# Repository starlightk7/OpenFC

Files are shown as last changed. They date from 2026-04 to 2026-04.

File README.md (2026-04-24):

# OpenFC

## Introduction

This repository contains OSHW Reproduction Parts related to the Famicom (FC) game console under the umbrella name OpenFC.

These parts are freely available under the terms of the [CERN-OHL-S](https://github.com/starlightk7/OpenFC/blob/main/LICENSE) license for you to use, study, modify, or sell. The source files are provided as-is with no warranty or entitlement for support to you or any users that you sell manufactured boards to. See [LICENSE](https://github.com/starlightk7/OpenFC/blob/main/LICENSE) and [NOTICE](https://github.com/starlightk7/OpenFC/blob/main/NOTICE) for details. Please carefully read these files to understand your obligations if you choose to distribute this project or modifications of it.

## Sample Build



## Usage

Suggested usage for the documents and boards in this repository:

* Studying the hardware and learning about it's function
* Aiding repairs and failure diagnostics through the created [schematics](https://starlightk7.github.io/OpenFC/#/schematic) and boardviews
* Repairing broken consoles via replacement, reproduction boards and tested replacement [BOMs](https://starlightk7.github.io/OpenFC/#/bom).
* Building a customized console as a DIY project, for hobby or educational purposes.

## Documentation

Please read the [documentation](https://starlightk7.github.io/OpenFC/) carefully before using the project.

You can also watch an HVC install video from [1upRestorations (English)](https://youtu.be/V8x1_Q33Uts)

## Getting a Board

The project officially distributes boards from [Japan (inexpensive international shipping available)](https://ko-fi.com/starlightk7/shop), the [US](https://1uprestorations.com/collections/console-mod-parts/) and the [UK](https://www.retroupgrades.co.uk/). If you just wish to simply obtain a board for yourself, it will often be cheaper than ordering from the fab directly.

***Support is offered to those who purchased a board from a vendor listed below. No support is provided for fabricating these files on your own. If you choose that route, you should understand what you are doing and are responsible for ensuring it is done right. I am not responsible for any defects that may arise from improperly manufacturing these files, or for defects arising from modifications made by you or your PCB fab during manufacturing. If you produce these boards for sale without becoming an authorized distributor, you are responsible for any and all customer support related to the product as well as your compliance with the project's license***. 

If you have any questions about this, feel free to contact with questions. If you are interested in becoming an authorized distributor for your region, and thus gaining support for your users, please contact me via Discord or Twitter.

The ultimate goal of this project is to eventually document and reproduce all models, but it will take quite some time. If you believe in the long term goal, consider subscribing on Ko-Fi; labor aside, donor boards to research, prototypes, and parts are all expensive, and those funds will help offset those costs to complete more boards.



Feel free to come chat with us on Discord: 

All boards in this project are ~40 years old at the time of writing. All relevant patents worldwide have long expired. This project is not affiliated with or endorsed by the big N.

## Commissions

I do not have time to build commissions on a regular basis, however, there are members of the retro community whom offer this service.

| US/Canada |
|-----------|
| [1upRestorations (United States)'](https://1uprestorations.com/) |

## Disclaimer

**WARNING:** Doing a full build is an advanced project. Please carefully read the documentation and required skills and experience before purchasing or ordering a board. Purchasing boards and parts does not guarantee that you can be successful in doing a build. Significant experience in soldering and desoldering, along with a variety of tools are necessary. Your first build will likely not work on its first boot. Patience, analysis, and debugging will likely be necessary to bring the unit online. Order at your own risk. The author provides no guarantee of your success, and also cannot guarantee that any given vendor can fabricate these boards correctly. If you are ordering boards, please consult with your target vendor before ordering if you wish to order a board.

## Parts Index

### Motherboards

| Part Number | Description | Region | Status| Japan | United States | United Kingdom |
|---|---|---|---|---|---|---|
| HVC-CPU-01 | AV Famicom / New Famicom | NTSC-J | Need Donor  | N/A | N/A | N/A |
| HVC-CPU-02 | AV Famicom / New Famicom | NTSC-J | Need Donor  | N/A | N/A | N/A |
| HVC-CPU-03 | AV Famicom / New Famicom | NTSC-J | Planned | N/A | N/A | N/A |
| HVC-CPU-04 | AV Famicom / New Famicom | NTSC-J | Planned | N/A | N/A | N/A |
| HVC-CPU-05 | AV Famicom / New Famicom | NTSC-J | Planned | N/A | N/A | N/A |
| HVC-CPU-06 | AV Famicom / New Famicom | NTSC-J | Planned | N/A | N/A | N/A |
| HVC-CPU-07 (1984) | The most common HVC motherboard. Most often comes with Rev. E chips. | NTSC-J | Released | [Ko-Fi (Direct)](https://ko-fi.com/starlightk7/shop), [eBay (Direct)](https://www.ebay.com/usr/starlightk7), [Etsy (Direct)](https://starlightretro.etsy.com) | [1upRestorations](https://1uprestorations.com/collections/console-mod-parts) | [RetroUpgrades](https://www.retroupgrades.co.uk/product/opensfc-shvc-bundle) |
| HVC-CPU-GPM-01 | Redesign that worked on lowering EMI for VCCI compliance | NTSC-J | Planned | N/A | N/A | N/A |
| HVC-CPU-GPM-02 | Redesign that worked on lowering EMI for VCCI compliance | NTSC-J | Planned | N/A | N/A | N/A |
| HVCN-CPU-01 | AV Famicom / New Famicom | NTSC-J | Need Donor  | N/A | N/A | N/A |
| HVCN-CPU-02 | AV Famicom / New Famicom | NTSC-J | In Progress | N/A | N/A | N/A |

### Power AV

| Part Number | Description | Region | Status| Japan | United States | United Kingdom |
|---|---|---|---|---|---|---|
| KP-782 | Early Type Original Power / RF Board | NTSC-J | Planned | N/A | N/A | N/A |
| KP-917 | Late Type Original Power / RF Board | NTSC-J | In Testing | N/A | N/A | N/A |
| OFC-PWRAV-01 | Original Design. Backport of SFC-style Power/Audio circuit w/ THS7314 for Composite Video. | NTSC-J | Released | [Ko-Fi (Direct)](https://ko-fi.com/starlightk7/shop), [eBay (Direct)](https://www.ebay.com/usr/starlightk7), [Etsy (Direct)](https://starlightretro.etsy.com) | [1upRestorations](https://1uprestorations.com/collections/console-mod-parts) | [RetroUpgrades](https://www.retroupgrades.co.uk/product/opensfc-shvc-bundle) |

### Controllers

| Part Number | Description | Region | Status| Japan | United States | United Kingdom |
|---|---|---|---|---|---|---|
| 56.8231A | Found in Early Circle Button Controllers Pre-NES Launch | NTSC-J | Planned | N/A | N/A | N/A |
| 56.8231B | Found in Most Circle Buttton Controllers. Official NES Support | NTSC-J / NTSC-U | Released | [Ko-Fi (Direct)](https://ko-fi.com/starlightk7/shop), [eBay (Direct)](https://www.ebay.com/usr/starlightk7), [Etsy (Direct)](https://starlightretro.etsy.com) | [1upRestorations](https://1uprestorations.com/collections/console-mod-parts) | [RetroUpgrades](https://www.retroupgrades.co.uk/product/opensfc-shvc-bundle) |
| 56.8232A  | Circle Button Player 2 Controller | NTSC-J | Released | [Ko-Fi (Direct)](https://ko-fi.com/starlightk7/shop), [eBay(Direct)](https://www.ebay.com/usr/starlightk7) | [1upRestorations](https://1uprestorations.com/collections/console-mod-parts) | [RetroUpgrades](https://www.retroupgrades.co.uk/) |

### Cartridges

There are none currently in progress, but they are planned for future.

### Accessories

There are none currently in progress, but they planned for future.

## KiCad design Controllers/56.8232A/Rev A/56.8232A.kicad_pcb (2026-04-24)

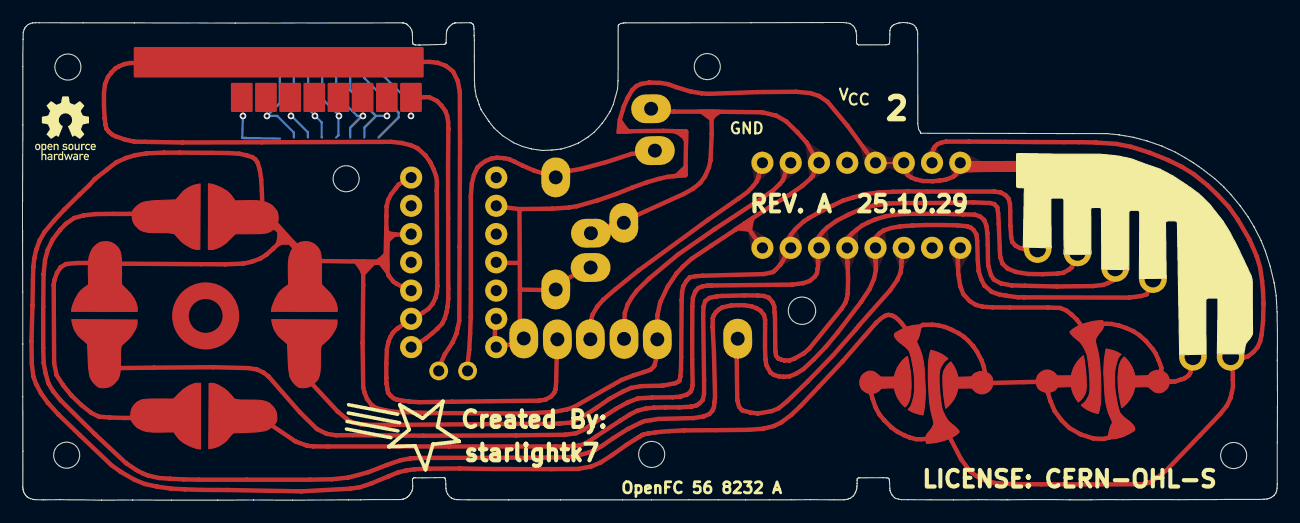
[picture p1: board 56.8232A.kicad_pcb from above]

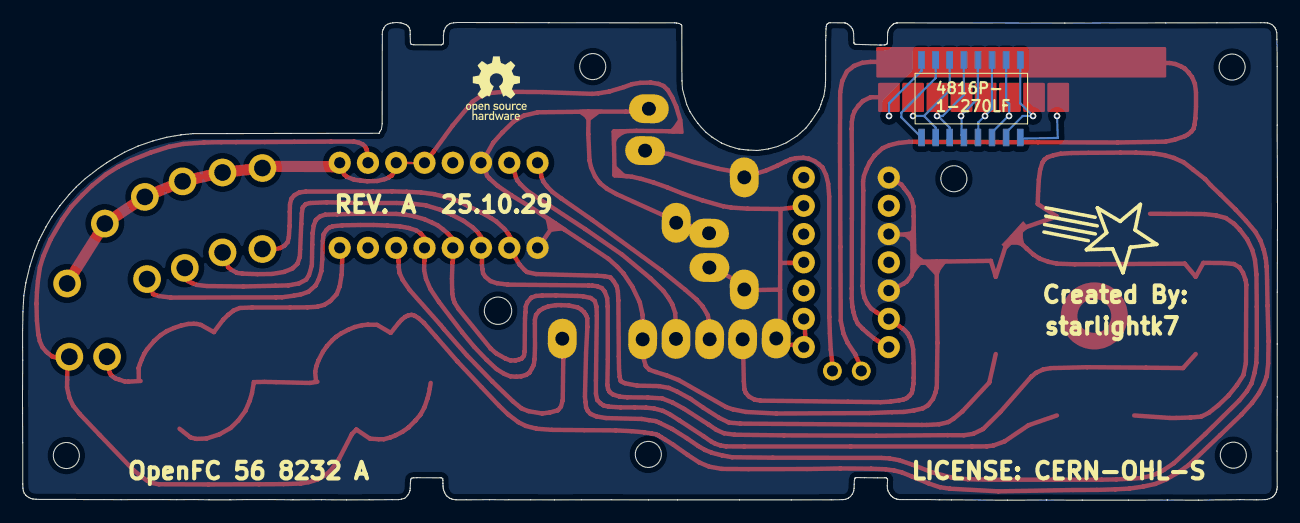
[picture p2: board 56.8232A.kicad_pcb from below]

Board: 2 copper layers, 113.0 x 43.0 mm, 23 parts (4 on the bottom side), 21 nets.

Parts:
C1: 0.33uf; C_THT_Small
IC1: IC4021
IC2: MIC_IC
J1, J2, J3, J4, J5, J7, J8, J9, J11, J12, J13: +5V; P1_Wire
R1: 2.2k; R_THT_Alt_Long
RN1: 40k x6; P2_CarbonTraces
RN2: 27ohm x8 SOIC; R_Array_08_SOIC16
S1: LEFT; P1_DPad
S3: UP; P1_DPad
S4: RIGHT; P1_DPad
S5: DOWN; P1_DPad
S9: B; P1_AB
S10: A; P1_AB

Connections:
GND: IC1.8 (GND), IC1.11 (GND), IC2.3 (I2), IC2.5 (I3), IC2.7 (VSS), J4.1, J8.1, J9.1, J12.1, S1.2 (Out), S3.2 (Out), S4.2 (Out), S5.2 (Out), S9.2 (Out), S10.2 (Out)
unnamed: IC1.1 (A), RN1.10, S10.1 (In)
unnamed: IC1.15 (B), RN1.12, S9.1 (In)
unnamed: IC1.10 (CLK), J3.1
unnamed: IC1.3 (Data), J13.1
unnamed: IC1.5 (Down), RN1.6, S5.1 (In)
unnamed: IC1.9 (Latch), J2.1
unnamed: IC1.6 (Left), RN1.4, S1.1 (In)
unnamed: IC1.7 (Right), RN1.2, S4.1 (In)
unnamed: IC1.4 (Up), RN1.8, S3.1 (In)
unnamed: IC2.1 (I1), RN2.16 (R1.2)
unnamed: C1.2, IC2.2 (O1), J1.1
unnamed: C1.1, J11.1, R1.1
unnamed: RN2.1 (R1.1), RN2.15 (R2.2)
unnamed: RN2.2 (R2.1), RN2.14 (R3.2)
unnamed: RN2.3 (R3.1), RN2.13 (R4.2)
unnamed: RN2.4 (R4.1), RN2.12 (R5.2)
unnamed: RN2.5 (R5.1), RN2.11 (R6.2)
unnamed: RN2.6 (R6.1), RN2.10 (R7.2)
unnamed: RN2.7 (R7.1), RN2.9 (R8.2)
VCC: IC1.13 (Start), IC1.14 (Sel.), IC1.16 (5V), IC2.9 (I4), IC2.11 (I5), IC2.13 (I6), IC2.14 (VDD), J5.1, J7.1, R1.2, RN1.1, RN1.3, RN1.5, RN1.7, RN1.9, RN1.11

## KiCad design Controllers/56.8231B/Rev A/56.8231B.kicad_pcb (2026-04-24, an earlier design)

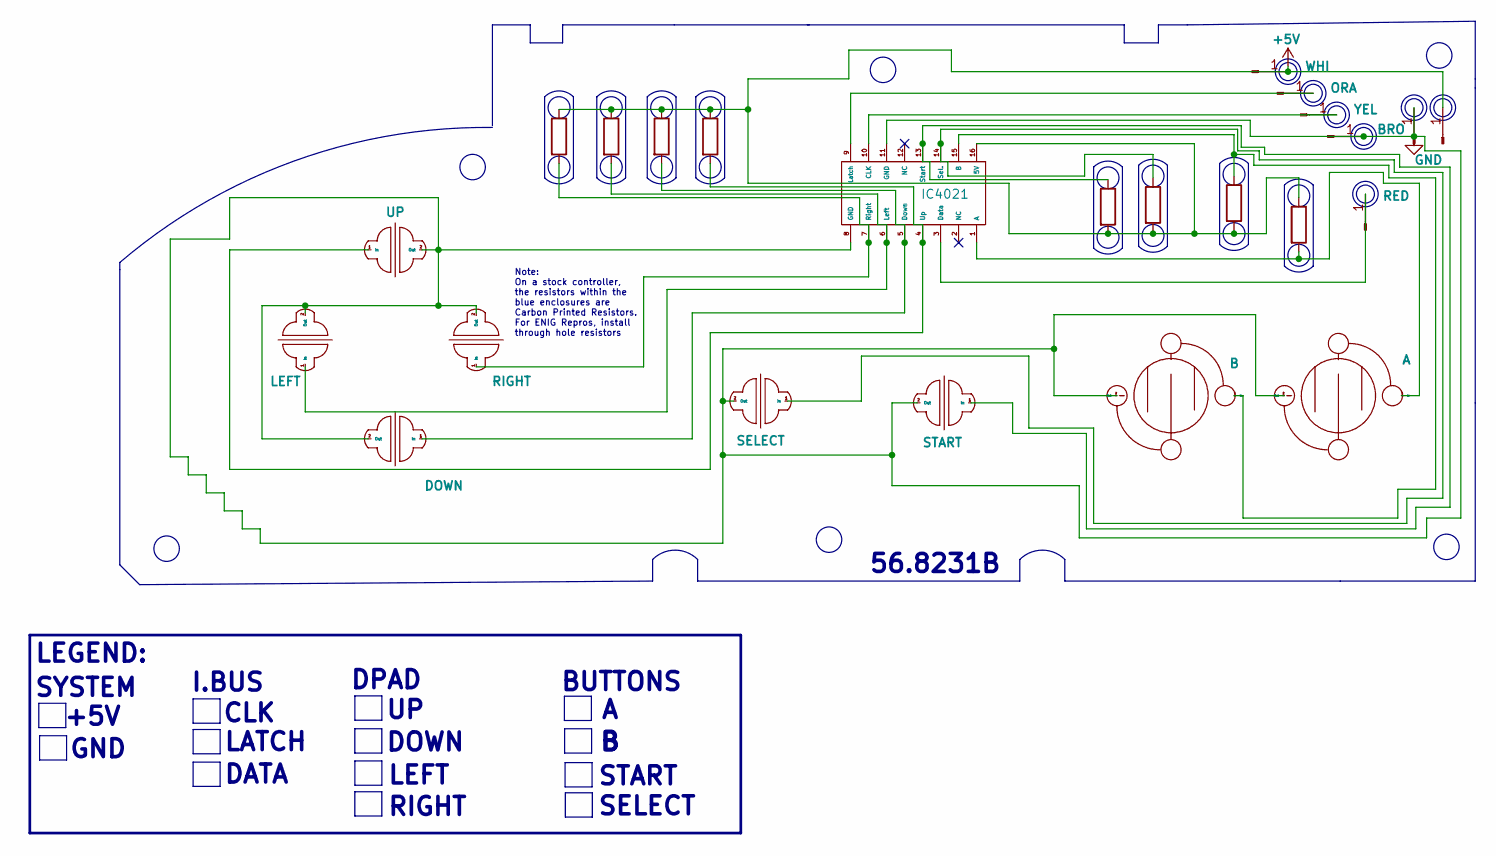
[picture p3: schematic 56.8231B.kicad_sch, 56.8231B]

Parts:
IC1: IC4021
J1: ORA; P1_Wire
J2: WHI; P1_Wire
J3: YEL; P1_Wire
J4: BRO; P1_Wire
J5: +5V; P1_Wire
J6: GND; P1_Wire
J7: RED; P1_Wire
R1, R2, R3, R4, R5, R6, R7, R8: R; CarbonResistor
S1: LEFT; P1_DPad
S2: SELECT; P1_SelectStart
S3: UP; P1_DPad
S4: RIGHT; P1_DPad
S5: DOWN; P1_DPad
S6: START; P1_SelectStart
S9: B; P1_AB
S10: A; P1_AB

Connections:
+5V: IC1.16 (5V), J2.1, J5.1, R1.1, R2.1, R3.1, R4.1, R5.2, R6.2, R7.2, R8.1
GND: IC1.8 (GND), IC1.11 (GND), J4.1, J6.1, S1.2 (Out), S2.2 (Out), S3.2 (Out), S4.2 (Out), S5.2 (Out), S6.2 (Out), S9.2 (Out), S10.2 (Out)
unnamed: IC1.1 (A), R8.2, S10.1 (In)
unnamed: IC1.15 (B), R7.1, S9.1 (In)
unnamed: IC1.10 (CLK), J3.1
unnamed: IC1.3 (Data), J7.1
unnamed: IC1.5 (Down), R3.2, S5.1 (In)
unnamed: IC1.9 (Latch), J1.1
unnamed: IC1.6 (Left), R2.2, S1.1 (In)
unnamed: IC1.7 (Right), R1.2, S4.1 (In)
unnamed: IC1.14 (Sel.), R6.1, S2.1 (In)
unnamed: IC1.13 (Start), R5.1, S6.1 (In)
unnamed: IC1.4 (Up), R4.2, S3.1 (In)

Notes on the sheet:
BUTTONS
START
LEFT
DOWN
Note: On a stock controller, the resistors within the blue enclosures are Carbon Printed Resistors. For ENIG Repros, install through hole resistors
DATA
56.8231B
LATCH
SELECT
DPAD
LEGEND:
+5V
SYSTEM
CLK
GND
RIGHT
I.BUS

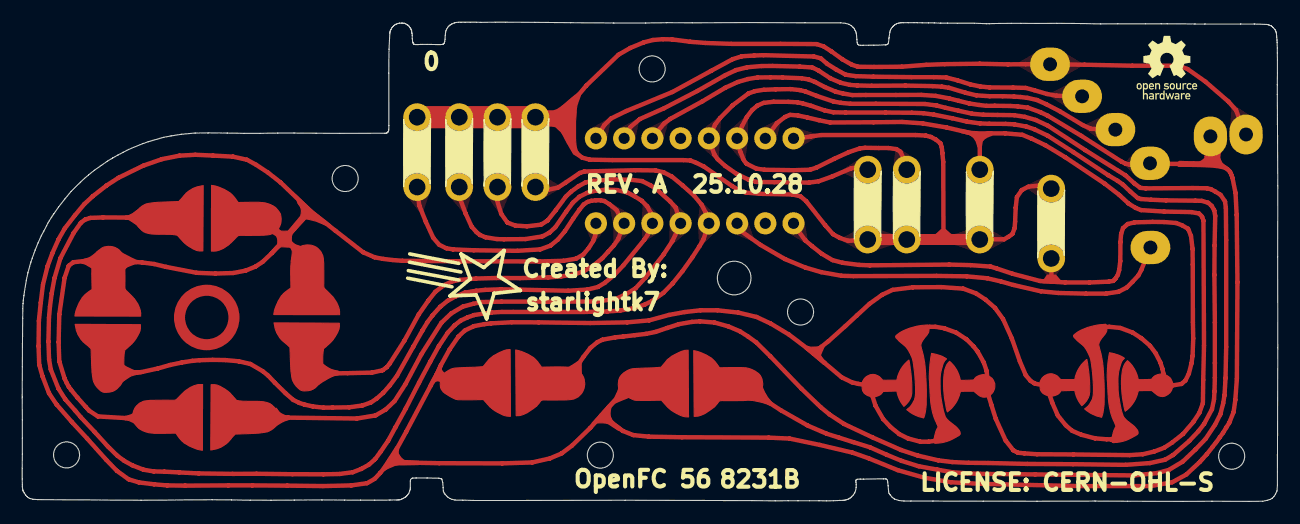
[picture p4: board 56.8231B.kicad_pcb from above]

Board: 2 copper layers, 113.2 x 43.2 mm, 24 parts (1 on the bottom side), 13 nets.

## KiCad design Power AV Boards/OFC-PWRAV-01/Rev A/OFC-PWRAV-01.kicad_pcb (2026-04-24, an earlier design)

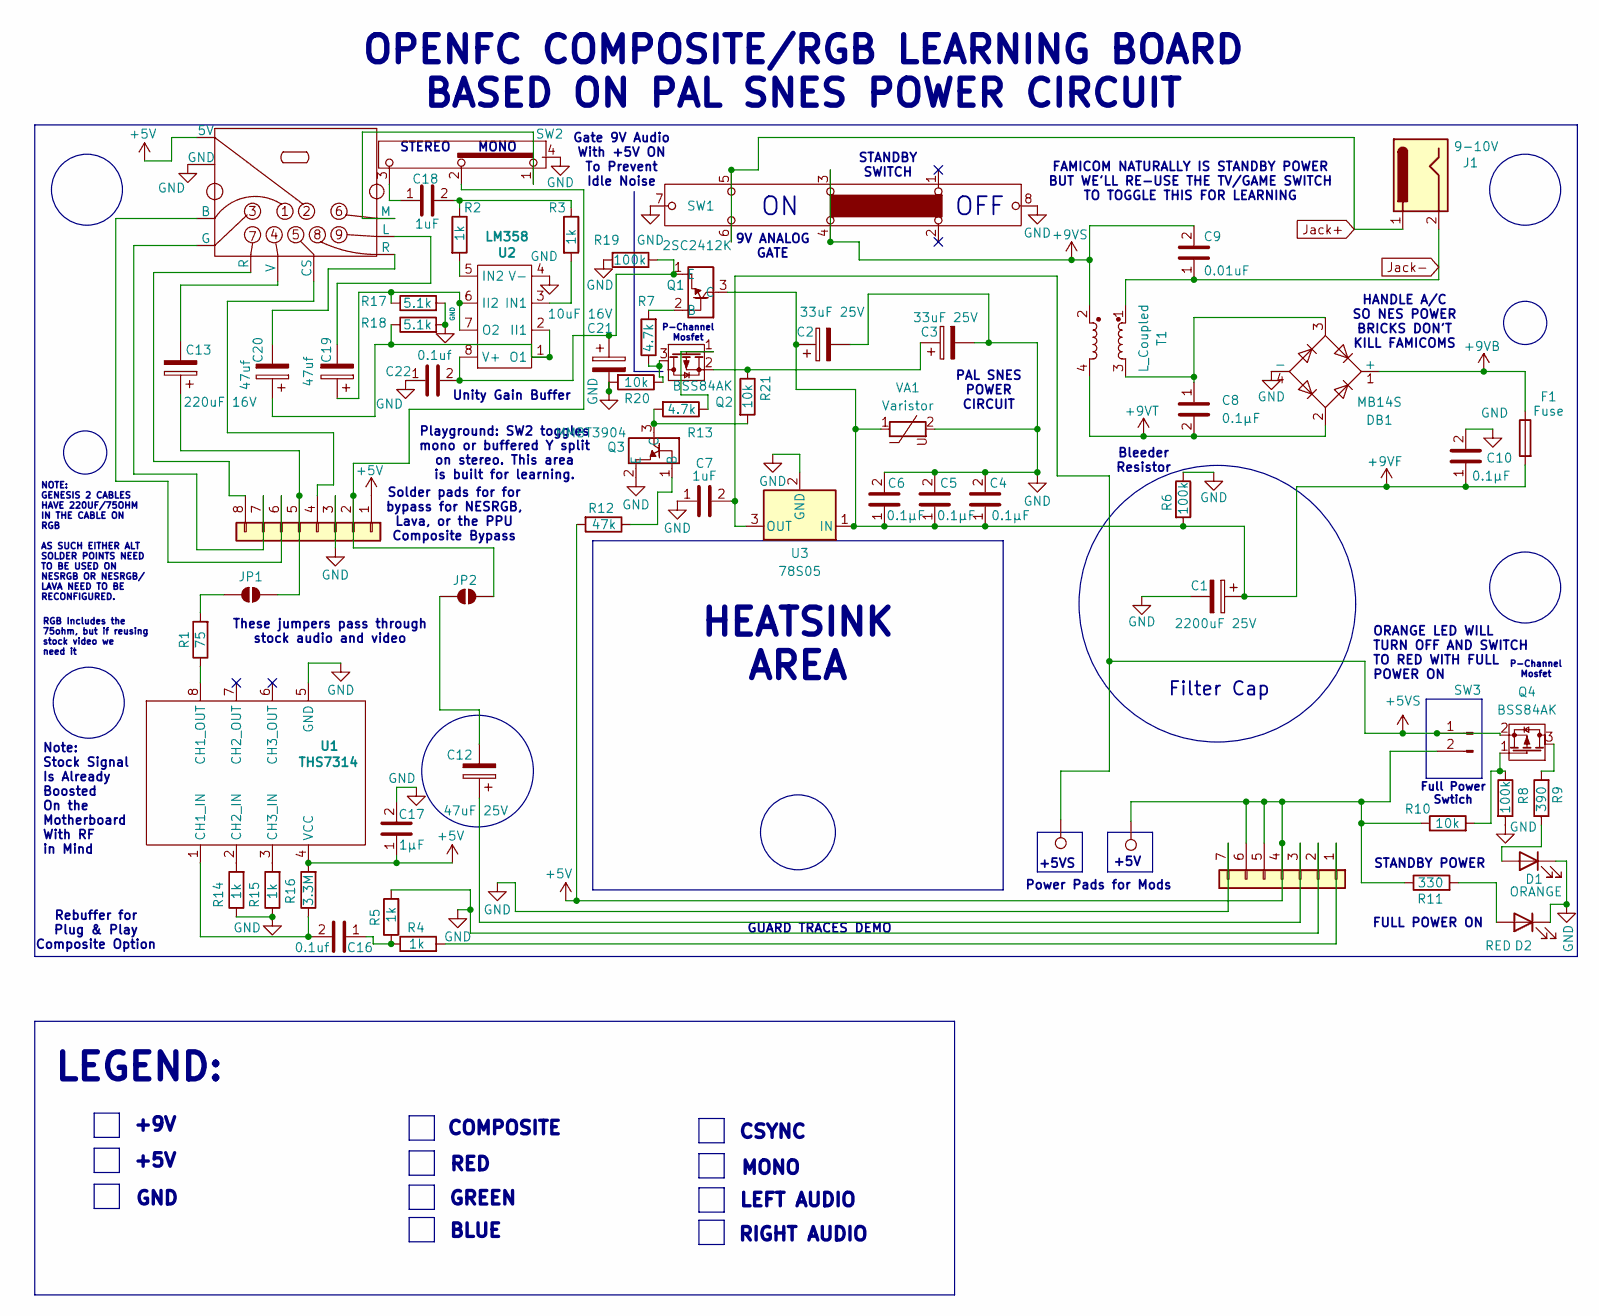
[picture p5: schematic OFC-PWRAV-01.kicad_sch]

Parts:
C1: 2200uF 25V; SFC_FilterCap
C2, C3: 33uF 25V; CP_Elec_6.3x3
C4, C5, C6, C8, C10: 0.1µF; SFC_SMD_0805
C7, C18: 1uF; SFC_SMD_0805
C9: 0.01uF; SFC_SMD_0805
C12: 47uF 25V; SFC_THT_Cap
C13: 220uF 16V; SFC_THT_Cap_S
C16, C22: 0.1uf; SFC_SMD_0805
C17: 1µF; SFC_SMD_0805
C19, C20: 47uf; SFC_THT_Cap
C21: 10uF 16V; SFC_SMD_CAP_S
D1: ORANGE; SFC_SMD_0805
D2: RED; SFC_SMD_0805
DB1: MB14S; Diode_Bridge_Vishay_MBLS
F1: Fuse; SFC_FUSE
J1: 9-10V; SFC_DCJack
J2, J3: Conn_01x07; HVC_Ribbon
J4: MD-90SM; DIN_9P; PARTREV 02/18/2022
JP1, JP2: SolderJumper_2_Open; SolderJumper-2_P1.3mm_Open_Pad1.0x1.5mm
Q1: 2SC2412K; Q_SOT
Q2, Q4: BSS84AK; Q_SOT_23
Q3: MMBT3904; Q_SOT_23
R1: 75; SFC_SMD_0805
R2, R3, R4, R5, R14, R15: 1k; SFC_SMD_0805
R6, R8, R19: 100k; SFC_SMD_0805
R7, R13: 4.7k; SFC_SMD_0805
R9: 390; SFC_SMD_0805
R10, R20, R21: 10k; SFC_SMD_0805
R11: 330; SFC_SMD_0805
R12: 47k; SFC_SMD_0805
R16: 3.3M; SFC_SMD_0805
R17, R18: 5.1k; SFC_SMD_0805
SW1: SW_TV_Game
SW2: SW_Channel
SW3: Conn_01x02_Pin; SFC_PowerSwitchConnector
T1: L_Coupled; SFC_T1
TP1, TP2: TestPoint; TestPoint_Pad_1.0x1.0mm
U1: THS7314; THS7134
U2: LM358; OpAmp
U3: 78S05; 7805_Heatsink
VA1: Varistor; SFC_SMD_Varistor

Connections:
+5V: C17.1, J2.4, J2.5, J2.6, J3.1 (+5VA), J4.2 (5V), R10.1, R11.1, R12.2, R16.2, SW3.2, TP2.1, U1.4 (VCC)
+5VS: C7.2, Q4.2 (S), SW3.1, TP1.1, U3.3 (OUT)
+9VB: DB1.1 (+), F1.1
+9VF: C1.1, C2.1, C4.1, C5.1, C6.1, C10.1, F1.2, Q1.3 (C), R6.2, U3.1 (IN), VA1.1
+9VS: C9.2, SW1.3, SW1.4, T1.2
+9VT: C8.2, DB1.2, T1.4
GND: C1.2, C2.2, C3.2, C4.2, C5.2, C6.2, C7.1, C10.2, C17.2, C21.2, C22.1, D1.1 (K), D2.1 (K), DB1.4 (-), J2.2, J2.7, J3.3 (AGND), J4.10 (GND), Q3.2 (E), R5.2, R6.1, R8.2, R14.1, R15.1, R17.2, R18.2, R19.2, R20.2, SW1.7, SW1.8, SW2.4, U1.5 (GND), U2.4 (V-), U3.2 (GND), VA1.2
Jack+: J1.1, SW1.5, SW1.6
Jack-: C9.1, J1.2, T1.1
unnamed: C8.1, DB1.3, T1.3
unnamed: C16.1, R4.1, R5.1
unnamed: C18.1, SW2.3
unnamed: C18.2, R2.1, R3.1
unnamed: C20.2, J4.8 (R)
unnamed: D1.2 (A), R9.1
unnamed: D2.2 (A), R11.2
unnamed: J2.1, R4.2
unnamed: C12.1, J2.3
unnamed: J3.2 (A), JP2.2 (B), SW2.2
unnamed: J3.4 (CS), J4.5 (CS)
unnamed: J3.7 (G), J4.3 (G)
unnamed: J3.8 (R), J4.7 (R)
unnamed: J3.6 (B), J4.1 (B)
unnamed: C19.2, J4.9 (L)
unnamed: J4.6 (M), SW2.1
unnamed: C13.2, J4.4 (V)
unnamed: JP1.1 (A), R1.2
unnamed: C13.1, J3.5 (B), JP1.2 (B)
unnamed: C12.2, JP2.1 (A)
unnamed: Q1.2 (B), R7.2
unnamed: C21.1, C22.2, Q1.1 (E), R19.1, U2.8 (V+)
unnamed: Q2.3 (D), R7.1, R20.1
unnamed: Q2.1 (G), R13.1
unnamed: C3.1, Q2.2 (S), R21.1
unnamed: Q3.1 (B), R12.1
unnamed: Q3.3 (C), R13.2, R21.2
unnamed: Q4.3 (D), R9.2
unnamed: Q4.1 (G), R8.1, R10.2
unnamed: C16.2, R16.1, U1.1 (CH1_IN)
unnamed: R1.1, U1.8 (CH1_OUT)
unnamed: R14.2, U1.2 (CH2_IN)
unnamed: R15.2, U1.3 (CH3_IN)
unnamed: C20.1, R18.1, U2.1 (O1), U2.2 (II1)
unnamed: C19.1, R17.1, U2.6 (II2), U2.7 (O2)
unnamed: R3.2, U2.3 (IN1)
unnamed: R2.2, U2.5 (IN2)

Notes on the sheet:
STEREO
STANDBY POWER
Solder pads for for bypass for NESRGB, Lava, or the PPU Composite Bypass
RIGHT AUDIO
9V ANALOG GATE
HANDLE A/C SO NES POWER BRICKS DON'T KILL FAMICOMS
+5V
Filter Cap
RGB Includes the 75ohm, but if reusing stock video we need it
P-Channel Mosfet
ORANGE LED WILL TURN OFF AND SWITCH TO RED WITH FULL POWER ON
RED
MONO
LEFT AUDIO
Unity Gain Buffer
PAL SNES POWER CIRCUIT
OFF
GUARD TRACES DEMO
FAMICOM NATURALLY IS STANDBY POWER BUT WE'LL RE-USE THE TV/GAME SWITCH TO TOGGLE THIS FOR LEARNING
Gate 9V Audio With +5V ON To Prevent Idle Noise
+5VS
NOTE: GENESIS 2 CABLES HAVE 220UF/75OHM IN THE CABLE ON RGB AS SUCH EITHER ALT SOLDER POINTS NEED TO BE USED ON NESRGB OR NESRGB/ LAVA NEED TO BE RECONFIGURED.
Note: Stock Signal Is Already Boosted On the Motherboard With RF in Mind
Playground: SW2 toggles mono or buffered Y split on stereo. This area is built for learning.
Rebuffer for Plug & Play Composite Option
COMPOSITE
CSYNC
Bleeder Resistor
HEATSINK AREA
Power Pads for Mods
These jumpers pass through stock audio and video
Full Power Swtich
LEGEND:
GND
+9V
STANDBY SWITCH
OPENFC COMPOSITE/RGB LEARNING BOARD BASED ON PAL SNES POWER CIRCUIT
GREEN
BLUE
FULL POWER ON

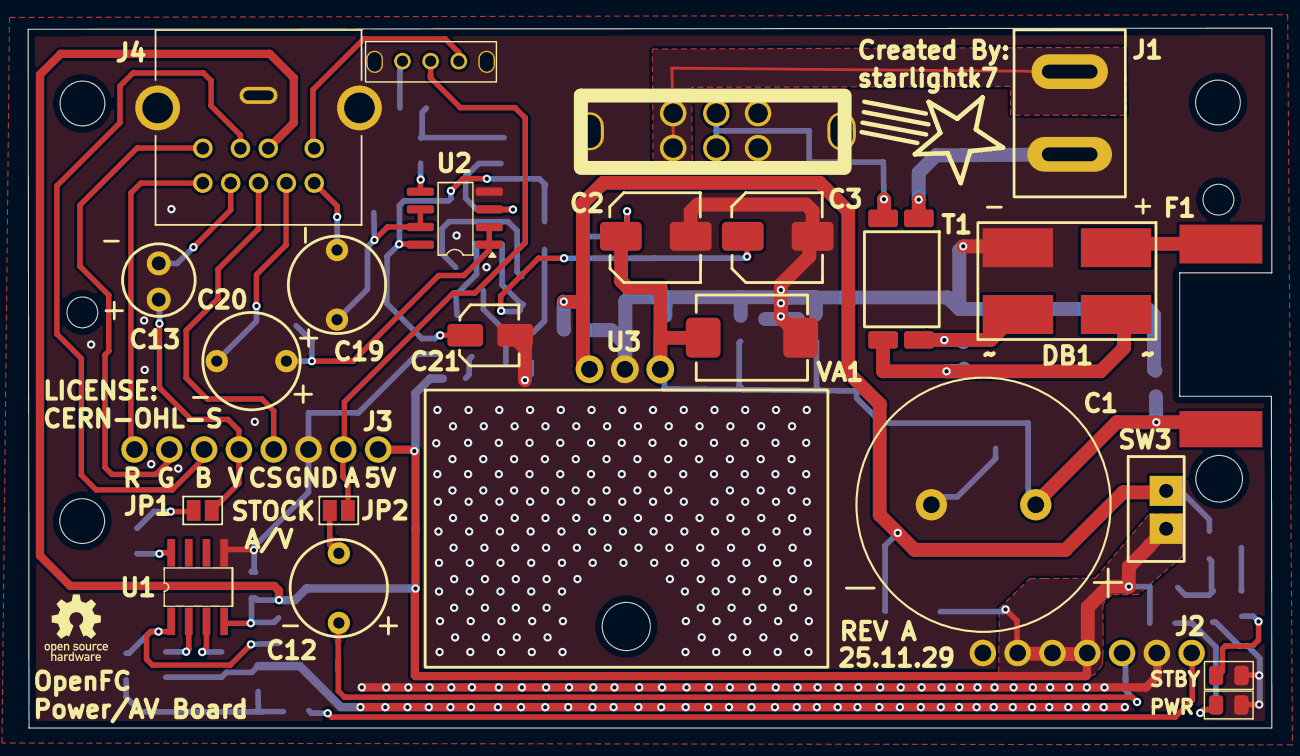
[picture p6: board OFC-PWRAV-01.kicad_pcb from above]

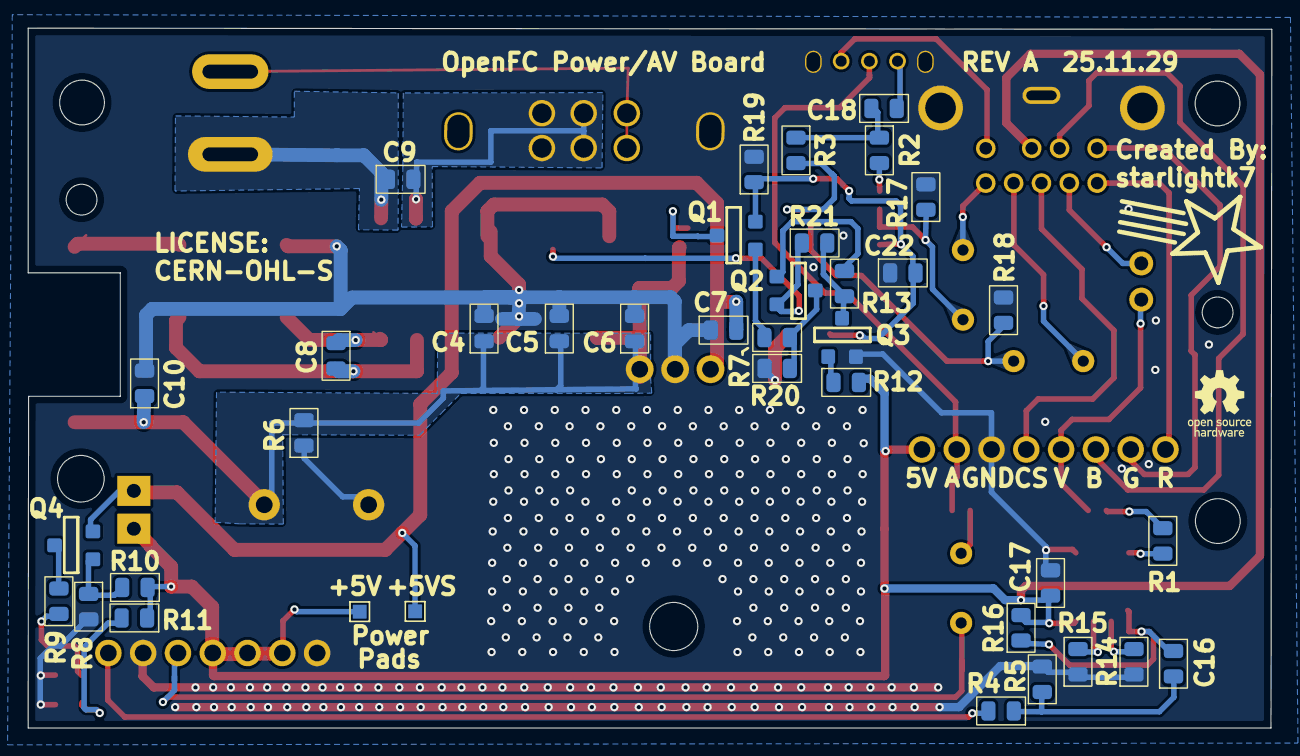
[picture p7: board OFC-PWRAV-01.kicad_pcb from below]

Board: 4 copper layers, 89.3 x 50.3 mm, 64 parts (38 on the bottom side), 46 nets.

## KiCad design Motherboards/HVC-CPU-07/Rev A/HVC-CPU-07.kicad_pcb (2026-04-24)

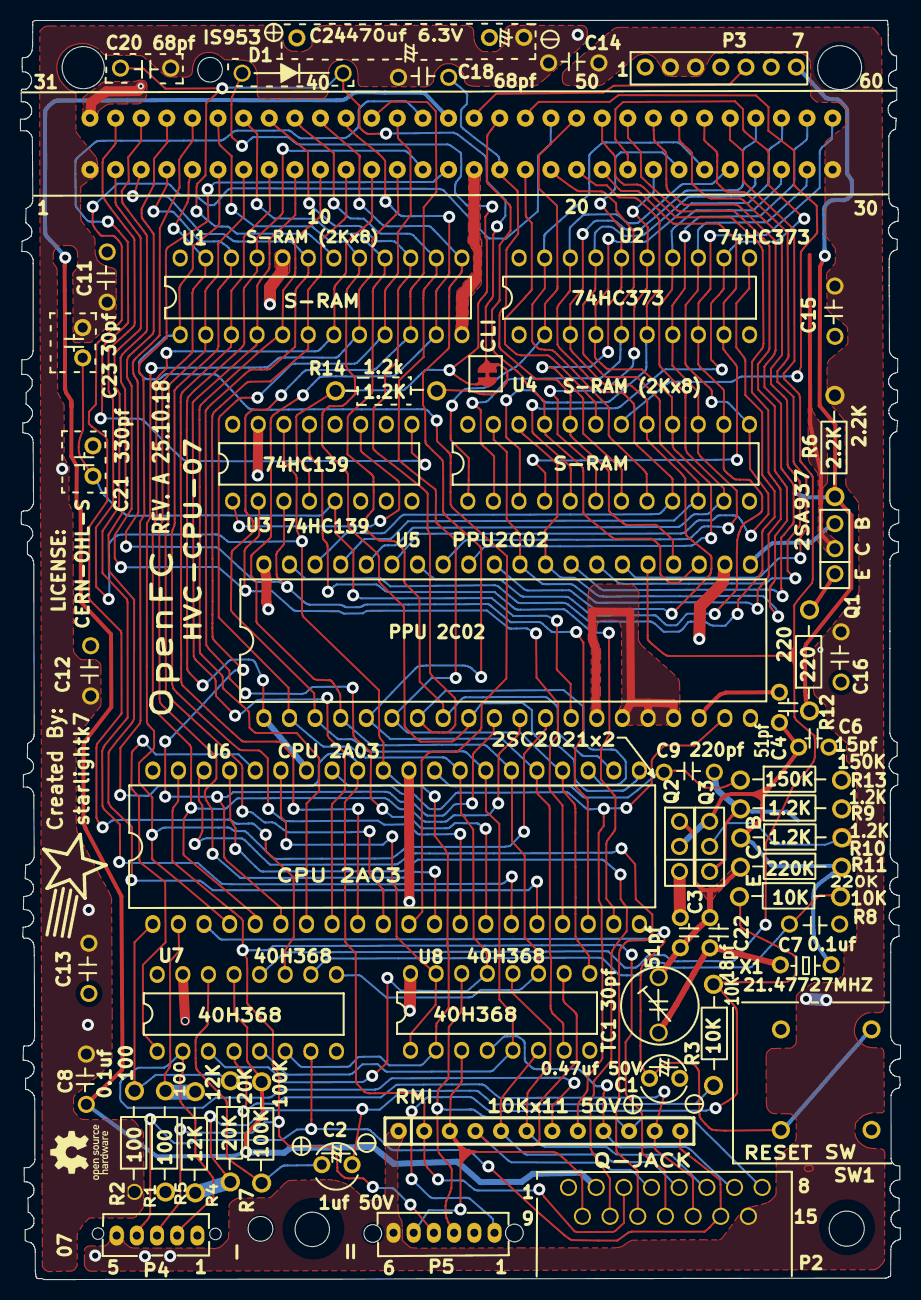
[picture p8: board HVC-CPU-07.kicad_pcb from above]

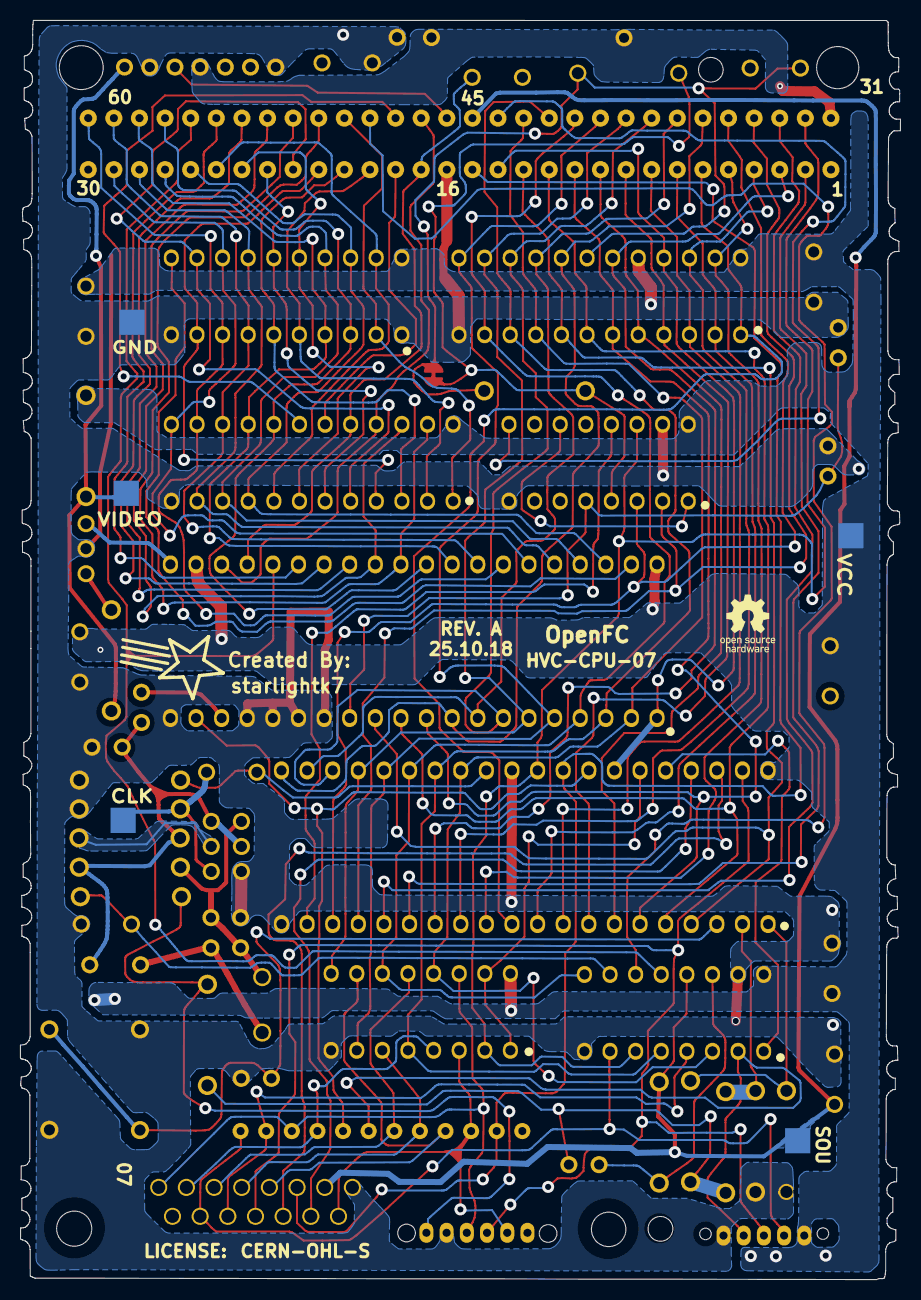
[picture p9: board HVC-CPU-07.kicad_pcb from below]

Board: 4 copper layers, 87.3 x 124.9 mm, 60 parts (5 on the bottom side), 95 nets.

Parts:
C1: 0.47uf 50V; C_Electrolytic
C2: 1uf 50V; C_Electrolytic_Small
C3, C4: 51pf; C_THT_Small
C6: 15pf; C_THT_Small
C7, C8, C11, C12, C13, C14, C15, C16: 0.1uf; C_THT
C9: 220pf; C_THT
C18, C20: 68pf; C_THT
C21: 330pf; C_THT_Small
C22: 18pf; C_THT_Small
C23: 30pf; C_THT_Small
C24: 470uf 6.3V; C_Axial
D1: Diode_THT
P1: 60PinCartSlot
P2: Q-JACK; D-JACK
P3: Conn_01x07; P3_PowerRibbon
P4: Conn_01x05; P4_Controller1
P5: Conn_01x06; P5_Controller2
Q1: 2SA937; Q_THT
Q2, Q3: 25C2021; Q_THT
R1, R2: 100; R_THT
R3, R8: 10K; R_THT
R4: 20K; R_THT
R5: 12K; R_THT
R6: 2.2K; R_THT
R7: 100K; R_THT
R9, R10, R14: 1.2K; R_THT
R11: 220K; R_THT
R12: 220; R_THT
R13: 150K; R_THT
RM1: 10Kx11 50V; R_Array_SIP12
SW1: RESET SW; RESET_SW
TC1: 30pf; TC1
TP1, TP2, TP3, TP4, TP5: TestPoint_Pad_2.5x2.5mm
U1, U4: S-RAM (2Kx8); S-RAM_2Kx8
U2: 74HC373
U3: 74HC139; 74HC139_40H368
U5: PPU 2C02; CPU_PPU
U6: CPU 2A03; CPU_PPU
U7, U8: 40H368; 74HC139_40H368
X1: 21.47727MHZ; Crystal

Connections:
1G: U3.1 (1G), U3.11 (2Y1)
A.IN: C8.1, P1.45 (A.IN), P2.2, R7.1, TP5.1, U7.13 (2Y2)
AD1: R2.1, R4.1, U6.1 (AD1)
AD2: R1.1, R5.1, U6.2 (AD2)
ALE: U2.11 (LE), U5.39 (ALE)
C2: C2.2, R3.1, R4.2, R5.2
C3: C3.1, C22.2, Q2.3, R11.2, TC1.1
C.A0: P1.13 (C.A0), U1.8 (A0), U5.12 (C.A0), U6.4 (A0)
C.A1: P1.12 (C.A1), U1.7 (A1), U5.11 (C.A1), U6.5 (A1)
C.A2: P1.11 (C.A2), U1.6 (A2), U5.10 (C.A2), U6.6 (A2)
C.A4: P1.9 (C.A4), U1.4 (A4), U6.8 (A4)
C.A5: P1.8 (C.A5), U1.3 (A5), U6.9 (A5)
C.A6: P1.7 (C.A6), U1.2 (A6), U6.10 (A6)
C.A7: P1.6 (C.A7), U1.1 (A7), U6.11 (A7)
C.A8: P1.5 (C.A8), U1.23 (A8), U6.12 (A8)
C.A9: P1.4 (C.A9), U1.22 (A9), U6.13 (A9)
C.A10: P1.3 (C.A10), U1.19 (A10), U6.14 (A10)
C.A11: P1.2 (C.A11), U6.15 (A11)
C.A12: P1.33 (C.A12), U6.16 (A12)
C.A13: P1.34 (C.A13), U3.2 (1A), U6.17 (A13)
C.A14: P1.35 (C.A14), U3.3 (1B), U6.18 (A14)
C.A15: U3.13 (2B), U6.19 (A15)
CD0: P1.43 (C.D0), U1.9 (D0), U5.2 (C.D0), U6.28 (D0), U7.3 (1Y1), U8.13 (2Y2)
CD1: P1.42 (C.D1), U1.10 (D1), U5.3 (C.D1), U6.27 (D1), U7.5 (1Y2), U8.5 (1Y2)
CD2: P1.41 (C.D2), U1.11 (D2), U5.4 (C.D2), U6.26 (D2), U7.9 (1Y4), U8.11 (2Y1)
CD3: P1.40 (C.D3), U1.13 (D3), U5.5 (C.D3), U6.25 (D3), U8.7 (1Y3)
CD4: P1.39 (C.D4), U1.14 (D4), U5.6 (C.D4), U6.24 (D4), U8.9 (1Y4)
CD5: P1.38 (C.D5), U1.15 (D5), U5.7 (C.D5), U6.23 (D5)
CD6: P1.37 (C.D6), U1.16 (D6), U5.8 (C.D6), U6.22 (D6)
CD7: P1.36 (C.D7), U1.17 (D7), U5.9 (C.D7), U6.21 (D7)
CLK: C9.1, R13.2, U6.29 (CLK)
D1: C20.2, D1.1 (K), D1.2 (A), R14.1, R14.2, U1.18 (/CE), U3.4 (1Y0)
GND: C1.2, C3.2, C6.1, C7.1, C8.2, C11.1, C12.1, C13.2, C14.1, C15.1, C16.1, C18.1, C20.1, C21.1, C23.1, C24.2, P1.1 (GND), P1.16 (GND), P2.1, P3.1, P3.6, P4.1, P5.2, Q1.2, Q2.1, R1.2, R2.2, R9.1, R13.1, SW1.1, SW1.3, TP1.1, U1.12 (GND), U1.20 (/OE), U2.1 (/OE), U2.10 (GND), U3.8 (GND), U3.15 (2G), U4.12 (GND), U5.14 (EXT0), U5.15 (EXT1), U5.16 (EXT2), U5.17 (EXT3), U5.20 (GND), U6.20 (GND), U6.30 (TST), U7.8 (GND), U7.15 (/2G), U8.8 (GND)
IRQ: P1.15 (/IRQ), P2.3, RM1.2, U6.32 (/IRQ)
M2: P1.32 (M2), U3.14 (2A), U6.31 (M2), U7.6 (1A3), U8.2 (1A1)
NMI: RM1.8, U5.19 (/INT), U6.33 (/NMI)
unnamed: C22.1, TC1.2, X1.1
unnamed: P1.46 (A.OUT), P3.5
unnamed: P1.10 (C.A3), U1.5 (A3), U6.7 (A3)
unnamed: P1.47 (P.RW), U4.21 (/WE), U5.23 (/WR)
unnamed: P1.18 (R.A10), U4.19 (A10)
unnamed: Q1.1, R12.1
unnamed: C4.2, U5.18 (CLK)
OE1: U6.36 (/OE1), U7.1 (/1G)
OE2: U6.35 (/OE2), U8.1 (/1G), U8.15 (/2G)
OUT0: P2.12, P4.3, P5.4, U6.39 (OUT0)
OUT1: P2.11, U6.38 (OUT1)
OUT2: P2.10, U6.37 (OUT2)
P5.5: P2.9, P5.5, RM1.3, U8.3 (1Y1)
P.A13: P1.49 (P.A13), U7.11 (2Y1)
PA0: P1.25 (P.A0), U2.19 (Q7), U4.8 (A0)
PA1: P1.24 (P.A1), U2.16 (Q6), U4.7 (A1)
PA2: P1.23 (P.A2), U2.15 (Q5), U4.6 (A2)
PA3: P1.22 (P.A3), U2.12 (Q4), U4.5 (A3)
PA4: P1.21 (P.A4), U2.9 (Q3), U4.4 (A4)
PA5: P1.20 (P.A5), U2.6 (Q2), U4.3 (A5)
PA6: P1.19 (P.A6), U2.5 (Q1), U4.2 (A6)
PA7: P1.50 (P.A7), U2.2 (Q0), U4.1 (A7)
PA8: P1.51 (P.A8), U4.23 (A8), U5.30 (P.A8)
PA9: P1.52 (P.A9), U4.22 (A9), U5.29 (P.A9)
PA10: P1.53 (P.A10), U5.28 (P.A10)
PA11: P1.54 (P.A11), U5.27 (P.A11)
PA12: P1.55 (P.A12), U5.26 (P.A12)
PD0: P1.26 (P.D0), U2.18 (D7), U4.9 (D0), U5.38 (P.AD0)
PD1: P1.27 (P.D1), U2.17 (D6), U4.10 (D1), U5.37 (P.AD1)
PD2: P1.28 (P.D2), U2.14 (D5), U4.11 (D2), U5.36 (P.AD2)
PD3: P1.29 (P.D3), U2.13 (D4), U4.13 (D3), U5.35 (P.AD3)
PD4: P1.60 (P.D4), U2.8 (D3), U4.14 (D4), U5.34 (P.AD4)
PD5: P1.59 (P.D5), U2.7 (D2), U4.15 (D5), U5.33 (P.AD5)
PD6: P1.58 (P.D6), U2.4 (D1), U4.16 (D6), U5.32 (P.AD6)
PD7: P1.57 (P.D7), U2.3 (D0), U4.17 (D7), U5.31 (P.AD7)
R3: P5.1, R3.2, R8.2
R7: C2.1, R7.2, U7.14 (2A2)
R9: C9.2, Q3.1, R9.2, TP4.1
R.CE: P1.48 (R.CE), U4.18 (/CE)
RD: C18.2, P1.17 (/RD), U4.20 (/OE), U5.24 (/RD)
RM10: P2.8, P5.3, RM1.10, U8.14 (2A2)
RSEL: P1.44 (R.SEL), U3.9 (2Y3)
RST: C1.1, SW1.2, SW1.4, U6.3 (/RST)
R/W: P1.14 (R/W), U1.21 (/WE), U5.1 (R/W), U6.34 (R/W)
U7.2: P4.2, RM1.7, U7.2 (1A1)
U7.4: P2.13, RM1.11, U7.4 (1A2)
U7.7: P2.14, P4.4, RM1.12, U7.7 (1Y3)
U7.10: C7.2, R8.1, U7.10 (1A4)
U7.12: P1.56 (P.A13), U5.25 (P.A13), U7.12 (2A1)
U8.4: P2.7, RM1.9, U8.4 (1A2)
U8.6: P2.5, RM1.5, U8.6 (1A3)
U8.10: P2.4, RM1.4, U8.10 (1A4)
U8.12: P2.6, RM1.6, U8.12 (2A1)
VCC: C11.2, C12.2, C13.1, C14.2, C15.2, C16.2, P1.30 (VCC), P2.15, P3.2, P3.3, P4.5, P5.6, Q3.2, R6.1, R10.1, RM1.1, TP3.1, U1.24 (VCC), U2.20 (VCC), U3.16 (VCC), U4.24 (VCC), U5.22 (/RST), U5.40 (VCC), U6.40 (VCC), U7.16 (VCC), U8.16 (VCC)
VCC2: C24.1, C24.3, P1.31 (CART), P3.4
VID: P3.7, R6.2, R12.2, TP2.1
VOUT: Q1.3, U5.21 (V.OUT)
X1: C4.1, C6.2, Q2.2, Q3.3, R10.2, R11.1, X1.2
/CS: C21.2, C23.2, U3.5 (1Y1), U5.13 (/CS)

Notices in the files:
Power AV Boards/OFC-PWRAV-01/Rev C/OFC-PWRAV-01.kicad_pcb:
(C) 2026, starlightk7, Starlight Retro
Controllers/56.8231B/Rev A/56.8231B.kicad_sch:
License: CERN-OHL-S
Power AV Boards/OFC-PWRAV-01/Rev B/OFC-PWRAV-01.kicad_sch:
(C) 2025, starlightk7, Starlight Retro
